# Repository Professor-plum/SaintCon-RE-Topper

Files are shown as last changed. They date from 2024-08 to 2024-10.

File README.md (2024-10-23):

# SaintCon 2024 Badge RE Topper
A reverse engineering themed SaintCon 2024 badge topper

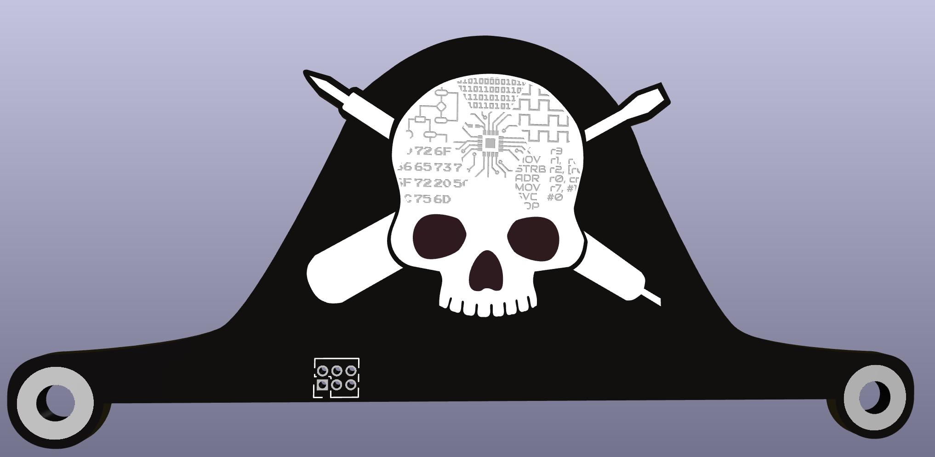
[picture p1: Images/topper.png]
Topper

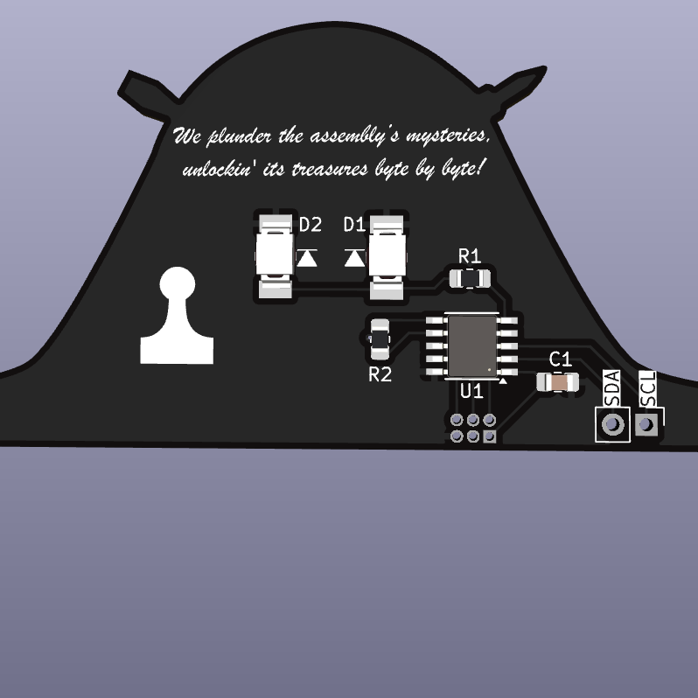
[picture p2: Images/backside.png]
Back Side


This topper can blink the LEDs in one of four patterns that can be selected by touching the skull (captive touch)
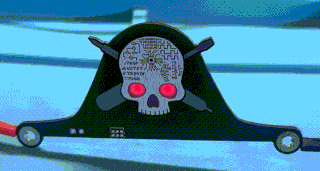
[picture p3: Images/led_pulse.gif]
Pulse
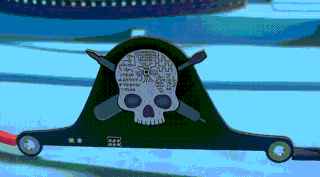
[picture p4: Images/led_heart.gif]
Heart
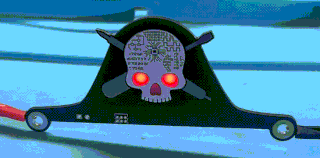
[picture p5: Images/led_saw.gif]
Saw
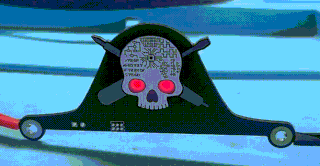
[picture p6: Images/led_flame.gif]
Flame
   

## Bill of Materials 
* 1x PY32F002AA15M
* 2x OSRAM TOPLED LS T77K LEDs
* 1x 470 Ohm 0805 Resistor
* 1x 1M Ohm 0805 Resistor
* 1x 1uF 0805 Capacitor

## Assembly instructions
1. Solder on the py32 microcontroller paying attention to pin 1 orientation
2. Solder on the 2 LEDs paying attention to direction. 
	- The black mark should be towards the bottom of the badge.
3. Solder on the 2 resistors, orientation doesn't matter
	- R1 is the 470 ohm resistor (4700 marking) 
	- R2 is the 1M ohm resistor (105 marking)
4. Solder on the capacitor, orientation doesn't matter

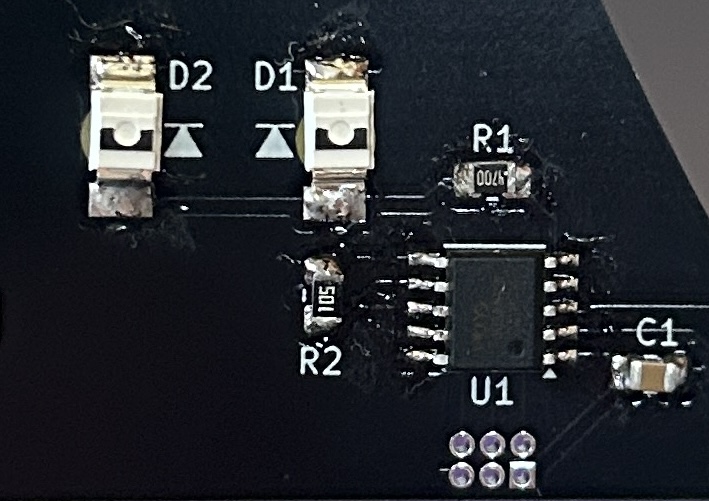
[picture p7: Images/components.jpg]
Soldering


## Flashing instructions
> [!NOTE]
>If you obtained the components during Saintcon the py32 is already flashed and you can skip the remainder of these steps.

Required hardware & software
- ST-Link V2 clone
- PyOCD [https://pyocd.io/](https://pyocd.io/) installed.

Connect 3.3V, GND, SWDIO, SWCLK, and RST to the ST-Link. These are all broken out on the 2x3 1.00mm pin header.
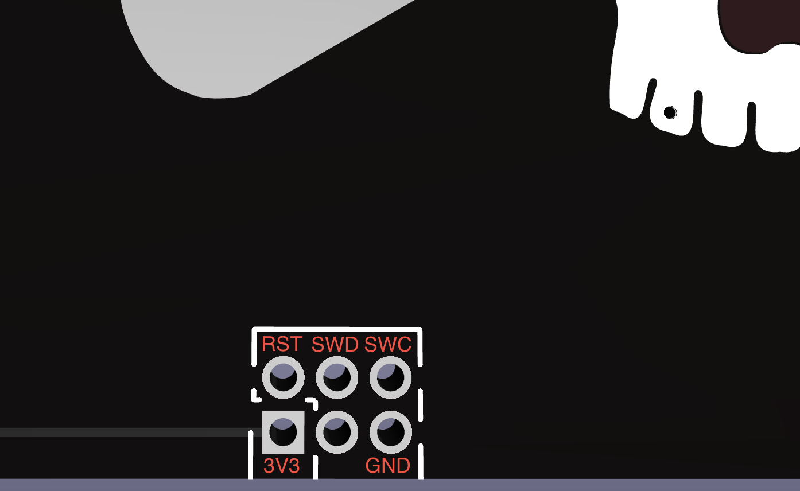
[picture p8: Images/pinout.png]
Pin out


To flash the MCU just execute `make flash` from the Fimware directory.

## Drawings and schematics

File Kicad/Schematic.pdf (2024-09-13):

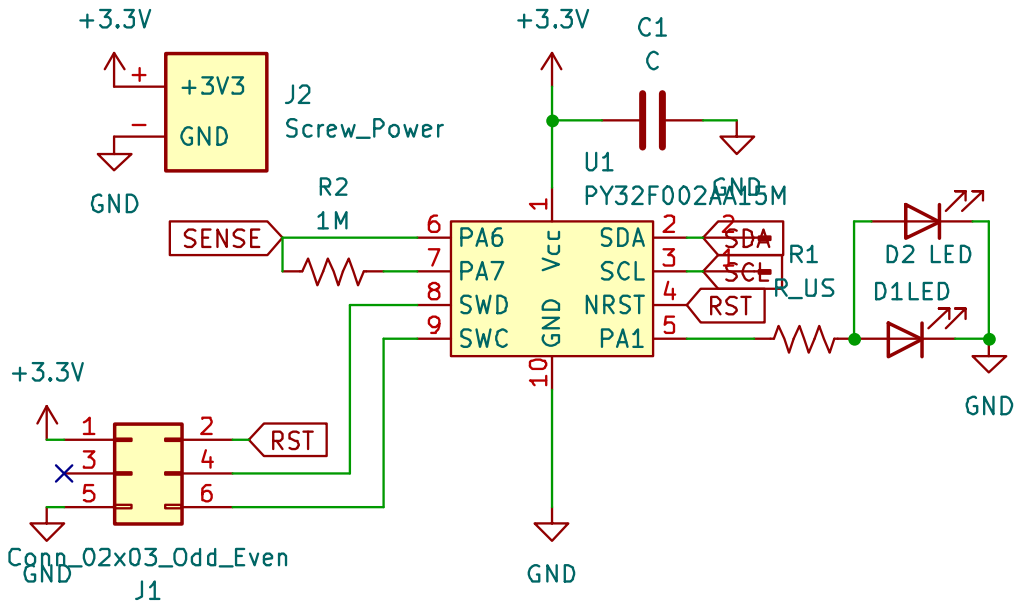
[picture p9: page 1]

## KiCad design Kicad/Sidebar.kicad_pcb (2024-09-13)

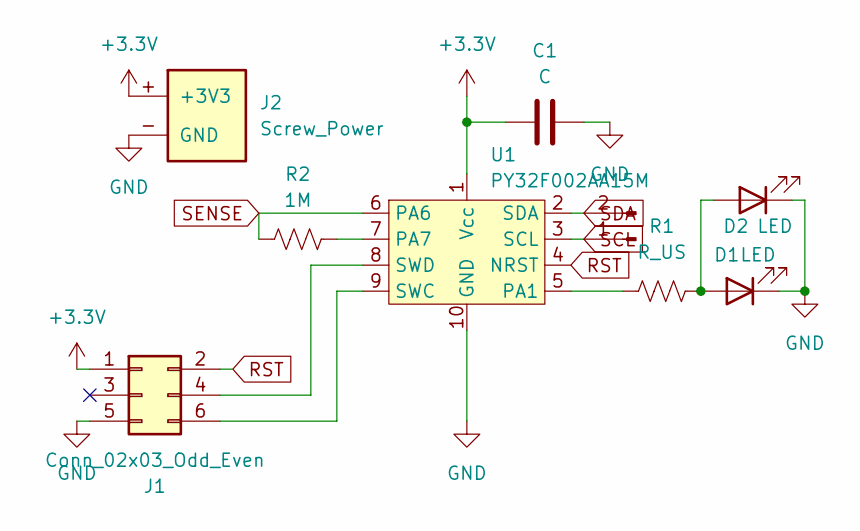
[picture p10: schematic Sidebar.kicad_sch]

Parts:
C1: C; C_0805_2012Metric_Pad1.18x1.45mm_HandSolder
D1, D2: LED; Reverse_LED
J1: Conn_02x03_Odd_Even; PinHeader_2x03_P1.27mm_Vertical
J2: Screw_Power; Saintcon2024Klip-onUpper
J3: Conn_01x02_Pin; PinHeader_1x02_P2.54mm_Vertical
R1: R_US; R_0805_2012Metric_Pad1.20x1.40mm_HandSolder
R2: 1M; R_0805_2012Metric_Pad1.20x1.40mm_HandSolder
U1: PY32F002AA15M; SSOP-10_3.9x4.9mm_P1.00mm

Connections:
+3.3V: C1.1, J1.1, J2.+ (+3V3), U1.1 (Vcc)
GND: C1.2, D1.1 (K), D2.1 (K), J1.5, J2.- (GND), U1.10 (GND)
unnamed: D1.2 (A), D2.2 (A), R1.1
unnamed: J1.4, U1.8 (SWD)
unnamed: J1.6, U1.9 (SWC)
unnamed: R1.2, U1.5 (PA1)
unnamed: R2.1, U1.7 (PA7)
RST: J1.2, U1.4 (NRST)
SCL: J3.1, U1.3 (SCL)
SDA: J3.2, U1.2 (SDA)
SENSE: R2.2, U1.6 (PA6)

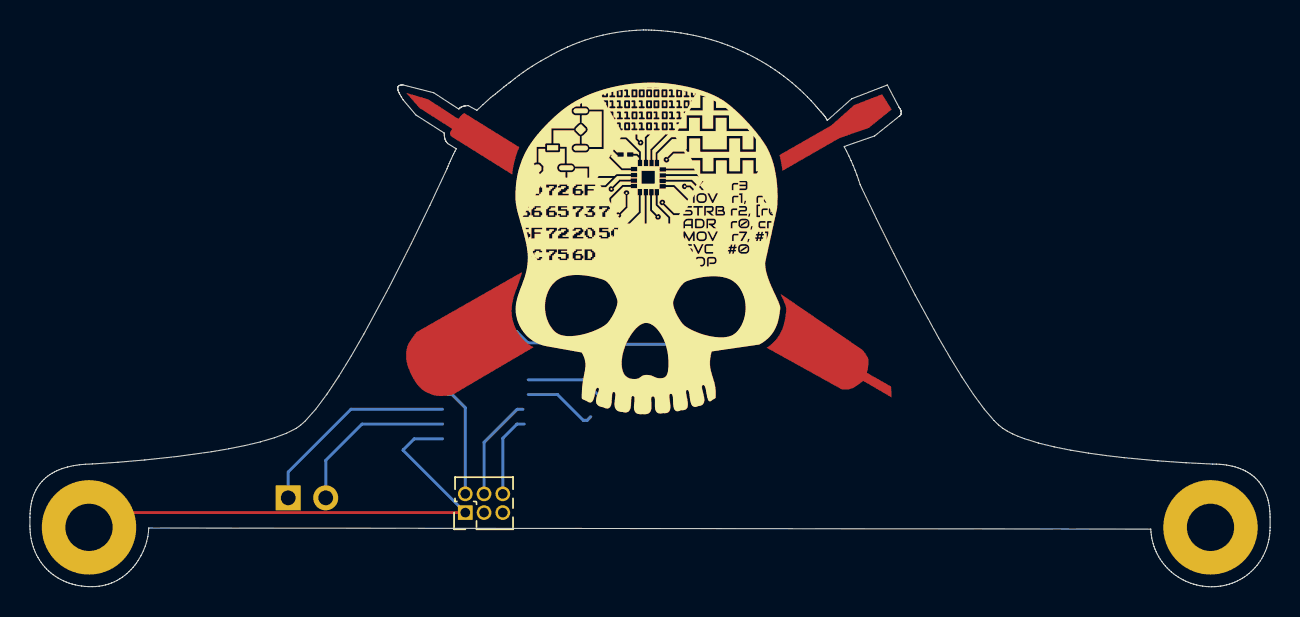
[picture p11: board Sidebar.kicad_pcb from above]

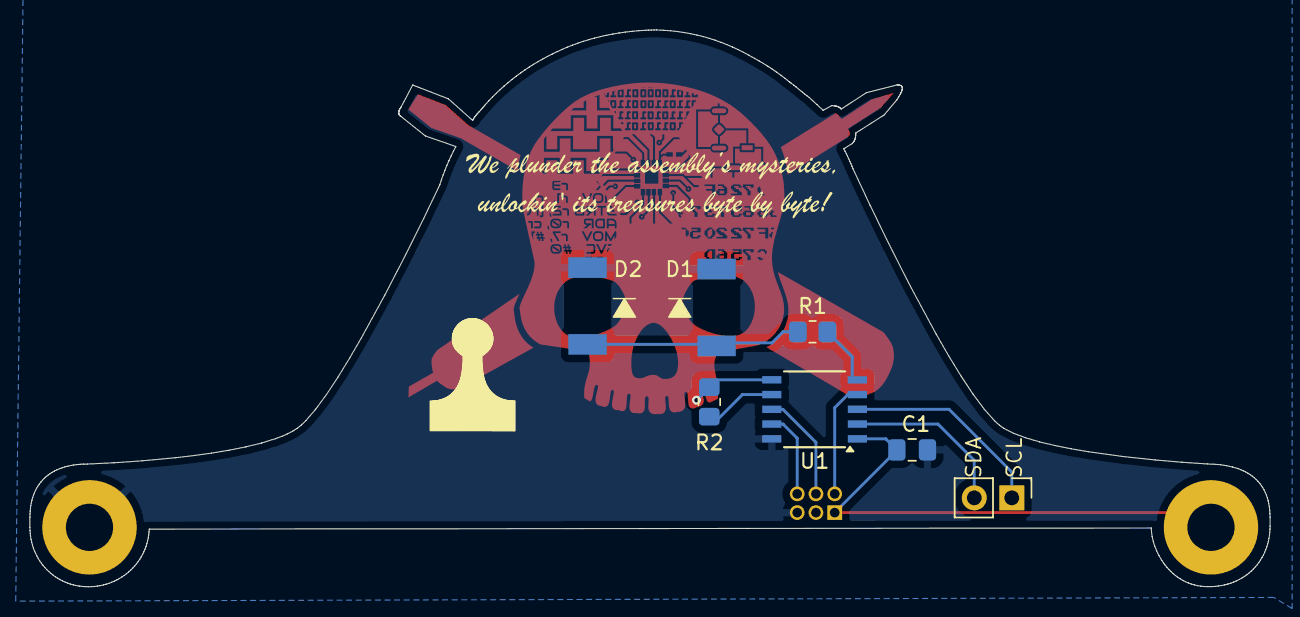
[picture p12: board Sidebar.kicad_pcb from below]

Board: 2 copper layers, 84.0 x 37.7 mm, 9 parts (7 on the bottom side), 11 nets.

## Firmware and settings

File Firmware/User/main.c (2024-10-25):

/***
 * Demo: TIM1 PWM 
 * 
 * CH1:PA8  -> CH1N:PA7
 * CH2:PA9  -> CH2N:PB0
 * CH3:PA10 -> CH3N:PB1
 */
#include "main.h"
#include "py32f0xx_bsp_clock.h"
#include "py32f0xx_bsp_printf.h"

static void APP_PWMChannelConfig(void);
static void APP_TIM1BaseConfig(void);
static void APP_I2CConfig(void);

int touch = 0;
int ptn=0;
#define PAT_COUNT 10


#define SENSE_PIN LL_GPIO_PIN_6
#define LOAD_PIN  LL_GPIO_PIN_7

#define MAX_COUNT 1024

int touch_sense() {
  int count1, count2;

  LL_GPIO_ResetOutputPin(GPIOA, SENSE_PIN);
  LL_GPIO_SetPinMode(GPIOA, SENSE_PIN, LL_GPIO_MODE_OUTPUT);
  LL_GPIO_SetPinOutputType(GPIOA, SENSE_PIN, LL_GPIO_OUTPUT_PUSHPULL);
  LL_GPIO_SetOutputPin(GPIOA, LOAD_PIN);

  LL_GPIO_SetPinMode(GPIOA, SENSE_PIN, LL_GPIO_MODE_INPUT);

  for (count1=0; count1<MAX_COUNT; ++count1) {
    if ((LL_GPIO_ReadInputPort(GPIOA) & SENSE_PIN)>0)
      break;
  }

  LL_GPIO_SetPinMode(GPIOA, SENSE_PIN, LL_GPIO_MODE_OUTPUT);
  LL_GPIO_SetPinOutputType(GPIOA, SENSE_PIN, LL_GPIO_OUTPUT_PUSHPULL);
  LL_GPIO_SetOutputPin(GPIOA, SENSE_PIN);
  LL_GPIO_ResetOutputPin(GPIOA, LOAD_PIN);

  LL_GPIO_SetPinMode(GPIOA, SENSE_PIN, LL_GPIO_MODE_INPUT);

  for (count2=0; count2<MAX_COUNT; ++count2) {
    if ((LL_GPIO_ReadInputPort(GPIOA) & SENSE_PIN) == 0)
      break;
  }

  return count1 + count2;
}

int ser_counter=6000;

int main(void)
{
  BSP_RCC_HSI_24MConfig();
  //BSP_USART_Config(115200);
  //printf("Touch\r\nClock: %ld \r\n", SystemCoreClock);

  APP_TIM1BaseConfig();
  APP_PWMChannelConfig();
  
  LL_IOP_GRP1_EnableClock(LL_IOP_GRP1_PERIPH_GPIOA);
  LL_GPIO_SetPinMode(GPIOA, LOAD_PIN, LL_GPIO_MODE_OUTPUT);
  LL_GPIO_SetPinOutputType(GPIOA, LOAD_PIN, LL_GPIO_OUTPUT_PUSHPULL);
  
  APP_I2CConfig();

  while (1)
  {
    int tally=0;
    for (int i=0; i<30; ++i) {
      tally += touch_sense();
    }

    printf("tally: %d \r\n", tally);
    if (tally > 2000) {
      if (touch == 0) {
        ptn= ((ptn + 1) % PAT_COUNT);
      }
      touch = 100;
    }
    else if (touch > 0) {
      touch--;
    }

    if (ser_counter == 500) {
      ResetI2CAddr();
    }
    else if (ser_counter < 500) {
      ser_counter++;
    }
    //LL_GPIO_TogglePin(GPIOA, LL_GPIO_PIN_1);
    //LL_mDelay(500);
  }
}

const uint16_t heart_pat[48] ={500,990,700,500,300,100,200,600,990,700,500,400,300,250,200,150,100,50,0,0,0,0,0,
  0,0,0,0,0,0,0,0,0,0,0,0,0,0,0,0,0,0,0,0,0,0};

const uint16_t triple_pat[48] = {990, 0, 990, 0, 990, 0, 0, 0, 0, 0, 0, 0};

const uint16_t long_pat[2] = {990, 0};

const uint16_t sineLookupTable[] = {
0x1f4, 0x200, 0x20c, 0x218, 0x224, 0x231, 0x23d, 0x249, 0x255, 0x261, 0x26d, 0x279, 0x284, 0x290, 0x29c, 0x2a7, 0x2b3, 0x2be, 0x2c9, 0x2d4, 0x2df, 0x2ea, 0x2f4, 0x2ff, 0x309, 0x313, 0x31d, 0x327, 0x330, 0x33a, 0x343, 0x34c,
0x355, 0x35d, 0x366, 0x36e, 0x376, 0x37d, 0x385, 0x38c, 0x393, 0x39a, 0x3a0, 0x3a6, 0x3ac, 0x3b2, 0x3b7, 0x3bc, 0x3c1, 0x3c6, 0x3ca, 0x3ce, 0x3d1, 0x3d5, 0x3d8, 0x3db, 0x3dd, 0x3e0, 0x3e2, 0x3e3, 0x3e5, 0x3e6, 0x3e6, 0x3e7,
0x3e7, 0x3e7, 0x3e6, 0x3e6, 0x3e5, 0x3e3, 0x3e2, 0x3e0, 0x3dd, 0x3db, 0x3d8, 0x3d5, 0x3d1, 0x3ce, 0x3ca, 0x3c6, 0x3c1, 0x3bc, 0x3b7, 0x3b2, 0x3ac, 0x3a6, 0x3a0, 0x39a, 0x393, 0x38c, 0x385, 0x37d, 0x376, 0x36e, 0x366, 0x35d,
0x355, 0x34c, 0x343, 0x33a, 0x330, 0x327, 0x31d, 0x313, 0x309, 0x2ff, 0x2f4, 0x2ea, 0x2df, 0x2d4, 0x2c9, 0x2be, 0x2b3, 0x2a7, 0x29c, 0x290, 0x284, 0x279, 0x26d, 0x261, 0x255, 0x249, 0x23d, 0x231, 0x224, 0x218, 0x20c, 0x200,
0x1f4, 0x1e7, 0x1db, 0x1cf, 0x1c3, 0x1b6, 0x1aa, 0x19e, 0x192, 0x186, 0x17a, 0x16e, 0x163, 0x157, 0x14b, 0x140, 0x134, 0x129, 0x11e, 0x113, 0x108, 0xfd, 0xf3, 0xe8, 0xde, 0xd4, 0xca, 0xc0, 0xb7, 0xad, 0xa4, 0x9b,
0x92, 0x8a, 0x81, 0x79, 0x71, 0x6a, 0x62, 0x5b, 0x54, 0x4d, 0x47, 0x41, 0x3b, 0x35, 0x30, 0x2b, 0x26, 0x21, 0x1d, 0x19, 0x16, 0x12, 0x0f, 0x0c, 0x0a, 0x07, 0x05, 0x04, 0x02, 0x01, 0x01, 0x00,
0x00, 0x00, 0x01, 0x01, 0x02, 0x04, 0x05, 0x07, 0x0a, 0x0c, 0x0f, 0x12, 0x16, 0x19, 0x1d, 0x21, 0x26, 0x2b, 0x30, 0x35, 0x3b, 0x41, 0x47, 0x4d, 0x54, 0x5b, 0x62, 0x6a, 0x71, 0x79, 0x81, 0x8a,
0x92, 0x9b, 0xa4, 0xad, 0xb7, 0xc0, 0xca, 0xd4, 0xde, 0xe8, 0xf3, 0xfd, 0x108, 0x113, 0x11e, 0x129, 0x134, 0x140, 0x14b, 0x157, 0x163, 0x16e, 0x17a, 0x186, 0x192, 0x19e, 0x1aa, 0x1b6, 0x1c3, 0x1cf, 0x1db, 0x1e7};

const uint16_t saw_pat[42] = {
  0, 50, 100, 150, 200, 250, 300, 350, 400, 450, 500, 550, 600, 650, 700, 750, 800, 850, 900, 950, 999, 
  999, 950, 900, 850, 800, 750, 700, 650, 600, 550, 500, 450, 400, 350, 300, 250, 200, 150, 100, 50, 0
};

const uint16_t halfsaw_pat[42] = {
  999, 950, 900, 850, 800, 750, 700, 650, 600, 550, 500, 450, 400, 350, 300, 250, 200, 150, 100, 50, 0,
  999, 950, 900, 850, 800, 750, 700, 650, 600, 550, 500, 450, 400, 350, 300, 250, 200, 150, 100, 50, 0
};

int rseed = 13;
uint16_t rand() {
  rseed = rseed * 75 + 74;
  return rseed;
}

int idx=0;
int flame = 100;
void APP_TIM1UpdateCallback(void)
{
  //LL_GPIO_TogglePin(GPIOA, LL_GPIO_PIN_6);
  if (ptn == 0) {
    LL_TIM_OC_SetCompareCH4(TIM1, sineLookupTable[(idx++) % 256]);
  }
  else if (ptn == 1) {
    LL_TIM_OC_SetCompareCH4(TIM1, heart_pat[(idx++/2) % 48]);
  }
  else if (ptn == 2){
    LL_TIM_OC_SetCompareCH4(TIM1, saw_pat[(idx++) % 42]);
  }
  else if (ptn == 3){
    flame = (rand()%40) + (flame * 4) / 5;
    LL_TIM_OC_SetCompareCH4(TIM1, flame);
  }
  else if (ptn == 4){
    LL_TIM_OC_SetCompareCH4(TIM1, triple_pat[(idx++/6) % 12]);
  }
  else if (ptn == 5){
    LL_TIM_OC_SetCompareCH4(TIM1, long_pat[(idx++/16) % 2]);
  }
  else if (ptn == 6){
    LL_TIM_OC_SetCompareCH4(TIM1, halfsaw_pat[(idx++) % 42]);
  }
  else if (ptn == 7){
    LL_TIM_OC_SetCompareCH4(TIM1, 500);
  }
  else if (ptn == 8){
    LL_TIM_OC_SetCompareCH4(TIM1, saw_pat[(idx++/4) % 42]);
  }
  else {
    LL_TIM_OC_SetCompareCH4(TIM1, 0);
  }
}


static void APP_I2CConfig(void) 
{
  LL_GPIO_InitTypeDef GPIO_InitStruct = {0};

  LL_IOP_GRP1_EnableClock(LL_IOP_GRP1_PERIPH_GPIOF);
  LL_APB1_GRP1_EnableClock(LL_APB1_GRP1_PERIPH_I2C1);

  NVIC_EnableIRQ(I2C1_IRQn);
  NVIC_SetPriority(I2C1_IRQn,0);
  
  // PF1 SCL , PF0 SDA
  GPIO_InitStruct.Pin = LL_GPIO_PIN_1 | LL_GPIO_PIN_0;
  GPIO_InitStruct.Mode = LL_GPIO_MODE_ALTERNATE;
  GPIO_InitStruct.Speed = LL_GPIO_SPEED_FREQ_HIGH;
  GPIO_InitStruct.OutputType = LL_GPIO_OUTPUT_OPENDRAIN;
  GPIO_InitStruct.Pull = LL_GPIO_PULL_UP;
  GPIO_InitStruct.Alternate = LL_GPIO_AF_12;
  LL_GPIO_Init(GPIOF, &GPIO_InitStruct);

  LL_APB1_GRP1_ForceReset(LL_APB1_GRP1_PERIPH_I2C1);
  LL_APB1_GRP1_ReleaseReset(LL_APB1_GRP1_PERIPH_I2C1);

  LL_I2C_InitTypeDef I2C_InitStruct;
  /*
   * Clock speed:
   * - standard = 100khz
   * - fast     = 400khz
  */
  I2C_InitStruct.ClockSpeed      = LL_I2C_MAX_SPEED_FAST;
  I2C_InitStruct.DutyCycle       = LL_I2C_DUTYCYCLE_2;
  I2C_InitStruct.OwnAddress1     = 0x50 << 1;
  I2C_InitStruct.TypeAcknowledge = LL_I2C_ACK;
  LL_I2C_Init(I2C1, &I2C_InitStruct);


  LL_I2C_Enable(I2C1);
  
  LL_I2C_EnableIT_EVT(I2C1); //Any event 
  //LL_I2C_EnableIT_ERR(I2C1); //Error INT

  SET_BIT(I2C1->CR2, I2C_CR2_ITEVTEN | I2C_CR2_ITBUFEN);
  
  /* Enable clock stretching */
  LL_I2C_EnableClockStretching(I2C1);

  /* Start out ACKnowledging incoming requests */
  LL_I2C_AcknowledgeNextData(I2C1, LL_I2C_ACK);
}

static void APP_PWMChannelConfig(void)
{
  LL_GPIO_InitTypeDef TIM1CH1MapInit= {0};
  LL_TIM_OC_InitTypeDef TIM_OC_Initstruct ={0};

  LL_IOP_GRP1_EnableClock(LL_IOP_GRP1_PERIPH_GPIOA);

  /* PA1 -> TIM1_CH4*/
  TIM1CH1MapInit.Pin        = LL_GPIO_PIN_1;
  TIM1CH1MapInit.Mode       = LL_GPIO_MODE_ALTERNATE;
  TIM1CH1MapInit.Alternate  = LL_GPIO_AF_13;
  LL_GPIO_Init(GPIOA, &TIM1CH1MapInit);

  TIM_OC_Initstruct.OCMode        = LL_TIM_OCMODE_PWM1;
  TIM_OC_Initstruct.OCState       = LL_TIM_OCSTATE_ENABLE;
  TIM_OC_Initstruct.OCPolarity    = LL_TIM_OCPOLARITY_HIGH;
  TIM_OC_Initstruct.OCIdleState   = LL_TIM_OCIDLESTATE_LOW;
  TIM_OC_Initstruct.CompareValue  = 999;

  LL_TIM_OC_Init(TIM1,LL_TIM_CHANNEL_CH4, &TIM_OC_Initstruct);
}

static void APP_TIM1BaseConfig(void)
{
  LL_TIM_InitTypeDef TIM1CountInit = {0};

  LL_APB1_GRP2_EnableClock(LL_APB1_GRP2_PERIPH_TIM1);
 
  TIM1CountInit.ClockDivision       = LL_TIM_CLOCKDIVISION_DIV1;
  TIM1CountInit.CounterMode         = LL_TIM_COUNTERMODE_UP;
  TIM1CountInit.Prescaler           = 300-1;
  TIM1CountInit.Autoreload          = 1000-1;
  TIM1CountInit.RepetitionCounter   = 0;
  LL_TIM_Init(TIM1,&TIM1CountInit);
  LL_TIM_EnableAllOutputs(TIM1);

  LL_TIM_EnableIT_UPDATE(TIM1);
  LL_TIM_EnableCounter(TIM1);

  NVIC_EnableIRQ(TIM1_BRK_UP_TRG_COM_IRQn);
  NVIC_SetPriority(TIM1_BRK_UP_TRG_COM_IRQn,0);
}

void APP_ErrorHandler(void)
{
  while (1);
}

#ifdef  USE_FULL_ASSERT
void assert_failed(uint8_t *file, uint32_t line)
{
  while (1);
}
#endif /* USE_FULL_ASSERT */

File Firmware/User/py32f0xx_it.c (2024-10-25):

#include "main.h"
#include "py32f0xx_it.h"
#include <stdbool.h>
#include <stdlib.h>

/**
  * @brief This function handles Non maskable interrupt.
  */
void NMI_Handler(void)
{
}

/**
  * @brief This function handles Hard fault interrupt.
  */
void HardFault_Handler(void)
{
  while (1)
  {
  }
}

/**
  * @brief This function handles System service call via SWI instruction.
  */
void SVC_Handler(void)
{
}

/**
  * @brief This function handles Pendable request for system service.
  */
void PendSV_Handler(void)
{
}

/**
  * @brief This function handles System tick timer.
  */
void SysTick_Handler(void)
{
}

void TIM1_BRK_UP_TRG_COM_IRQHandler(void)
{
  if(LL_TIM_IsActiveFlag_UPDATE(TIM1) && LL_TIM_IsEnabledIT_UPDATE(TIM1))
  {
    LL_TIM_ClearFlag_UPDATE(TIM1);
    APP_TIM1UpdateCallback();
  }
}


extern int ptn;

bool serialmode = 0;

const uint8_t memory_data[10][8] = {
  "ZSandals", 
  "Hydra   ", 
  "Scrooge ",
  "Greed   ",
  "ExtraDmg", 
  "GlassCan", 
  "RevShell", //Guess
  "SavingTh", //Guess
  "Simplify", //Guess
  "SpellChk"  //Guess
};

//"ZSandals",
//b'\t \x87\x04T\x10\x04R\x8cX\xa0\x80\xa0\x80\x00\x8e'

//b'Greed   '
//b'\t \x87\x04T\x10\x04P\xbc`\xa0\x80\xa0\x80\x00\t'
//b'\t \x87\x04T\x10\x04Q\x9cp\xa0\x80\xa0\x80\x00\xbc'

//b'Scrooge '
//b'\t \x87\x04T\x10\x04R\xb46\xa0\x80\xa0\x80\x00\xd2'
//b'\t \x87\x04T\x10\x04R\xd07\xa0\x80\xa0\x80\x00t',

//b'GlassCan' //could be lowercase C


/*
b'ExtraDmg'
b'\t \x87\x04T\x10\x04QLO\xa0\x80\xa0\x80\x00\xbb'
b'Hydra   '
b'\t \x87\x04T\x10\x04P\x9ca\xa0\x80\xa0\x80\x00\xa0'
b'SavingTh'
b'\t \x87\x04T\x10\x04Q`^\xa0\x80\xa0\x80\x00\x9e'
b'ZSandals'
b'\t \x87\x04T\x10\x04P\xe4n\xa0\x80\xa0\x80\x00\x87'
b'RevShell'
b'\t \x87\x04T\x10\x04P\x84&\xa0\x80\xa0\x80\x00\x8d'
b'Simplify'
b'\t \x87\x04T\x10\x04P\xc4e\xa0\x80\xa0\x80\x00\x18'
b'Scrooge '
b'\t \x87\x04T\x10\x04R4\x88\xa0\x80\xa0\x80\x00W'
b'Greed   '
b'\t \x87\x04T\x10\x04QDf\xa0\x80\xa0\x80\x00\xcc'
b'SpellChk'
b"\t \x87\x04T\x10\x04Qt'\xa0\x80\xa0\x80\x00\xf5"



*/

uint8_t rand_serial[16] = "\t \x87\x04T\x10\x06XXX\xa0\x80\xa0\x80\x00X";

const uint8_t serial_data[10][16] = {
  "\t \x87\x04T\x10\x04P\xe4n\xa0\x80\xa0\x80\x00\x87",
  "\t \x87\x04T\x10\x04P\x9c\x91\xa0\x80\xa0\x80\x00\xa0",
  "\t \x87\x04T\x10\x04R\xb4\x36\xa0\x80\xa0\x80\x00\xd2",
  "\t \x87\x04T\x10\x04QDf\xa0\x80\xa0\x80\x00\xcc",
  "\t \x87\x04T\x10\x04QLO\xa0\x80\xa0\x80\x00\xbb",
  "\t \x87\x04T\x10\x04R\xb4\x36\xa0\x80\xa0\x80\x00\xd2",
  "\t \x87\x04T\x10\x04P\x84&\xa0\x80\xa0\x80\x00\x8d",
  "\t \x87\x04T\x10\x04Q`^\xa0\x80\xa0\x80\x00\x9e",
  "\t \x87\x04T\x10\x04P\xc4\x60\xa0\x80\xa0\x80\x00\x18",
  "\t \x87\x04T\x10\x04Qt'\xa0\x80\xa0\x80\x00\xf5"
};

uint8_t i2c_idx;
extern int ser_counter;

void FlipI2CAddr() {
  //return;
  serialmode = !serialmode;
  if (serialmode) {
    LL_I2C_SetOwnAddress1(I2C1, 0x58 << 1, 0);
    rand_serial[7] = rand();
    rand_serial[8] = rand();
    rand_serial[9] = rand();
    rand_serial[15] = rand();
    ser_counter = 0;
  }
  else {
    LL_I2C_SetOwnAddress1(I2C1, 0x50 << 1, 0);
    ser_counter = 6000;
  }
}

void ResetI2CAddr() {
  serialmode = false;
  LL_I2C_SetOwnAddress1(I2C1, 0x50 << 1, 0);
  ser_counter = 6000;
}

void I2C1_IRQHandler(void)
{
  // A master is addressing us? 
  if (LL_I2C_IsActiveFlag_ADDR(I2C1))
  {
    // Clear the flag 
    LL_I2C_ClearFlag_ADDR(I2C1);
    
    i2c_idx=0;
  }
  // Stop condition flag set 
  else if (LL_I2C_IsActiveFlag_STOP(I2C1))
  {
    // Clear the flag 
    LL_I2C_ClearFlag_STOP(I2C1);
    // ACK the next byte addressed to us 
    //FlipI2CAddr();
    LL_I2C_AcknowledgeNextData(I2C1, LL_I2C_ACK);
  }
  // TX empty flag set 
  else if (LL_I2C_IsActiveFlag_TXE(I2C1))
  {
    if (serialmode) {
      LL_I2C_TransmitData8(I2C1, rand_serial[i2c_idx++ %16]); //serial_data[ptn][i2c_idx++ %16]);
      if ((i2c_idx % 16) == 0){
        FlipI2CAddr();
      }
    }
    else {
      LL_I2C_TransmitData8(I2C1, memory_data[ptn][i2c_idx++ %8]);
      if ((i2c_idx % 8) == 0) {
        FlipI2CAddr();
      }
    }
  }
  // RX not empty flag set 
  else if (LL_I2C_IsActiveFlag_RXNE(I2C1))
  {
    // Are we receiving the index? 
    LL_I2C_ReceiveData8(I2C1);
  }

  if(LL_I2C_IsActiveFlag_AF(I2C1)) {
    // End of Transfer 
    //FlipI2CAddr();
    LL_I2C_ClearFlag_AF(I2C1);
  }
}

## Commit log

2024-09-13 Updated Kicad Files
    [Sidebar.kicad_pcb, Sidebar.kicad_sch]
2024-09-30 Updated firmware and readme with LED patterns
2024-10-23 Update README.md
    Corrected resistor values to match what was delivered
